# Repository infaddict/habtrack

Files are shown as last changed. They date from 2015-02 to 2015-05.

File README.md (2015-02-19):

# habtrack
High Altitude Balloon Tracker 

Written by: infaddict

Project start date: February 2015

Description: Tracking software for High Altitude Ballooning.  Includes GPS location/altitude, internal & external temperature, voltage monitor, Radio transmission and optional data logging to SD card.  

Hardware: Arduino Mini Pro 3.3V 8Mhz, uBlox M8C GPS with chip antenna, Radiometrix NTX2B-FA, 2 x DS18B20 temperature sensors, microSD breakout board (SPI), various resistors

For more information visit the UK High Altitude Society here: http://ukhas.org.uk/

Also join us on IRC: irc://irc.freenode.net/highaltitude

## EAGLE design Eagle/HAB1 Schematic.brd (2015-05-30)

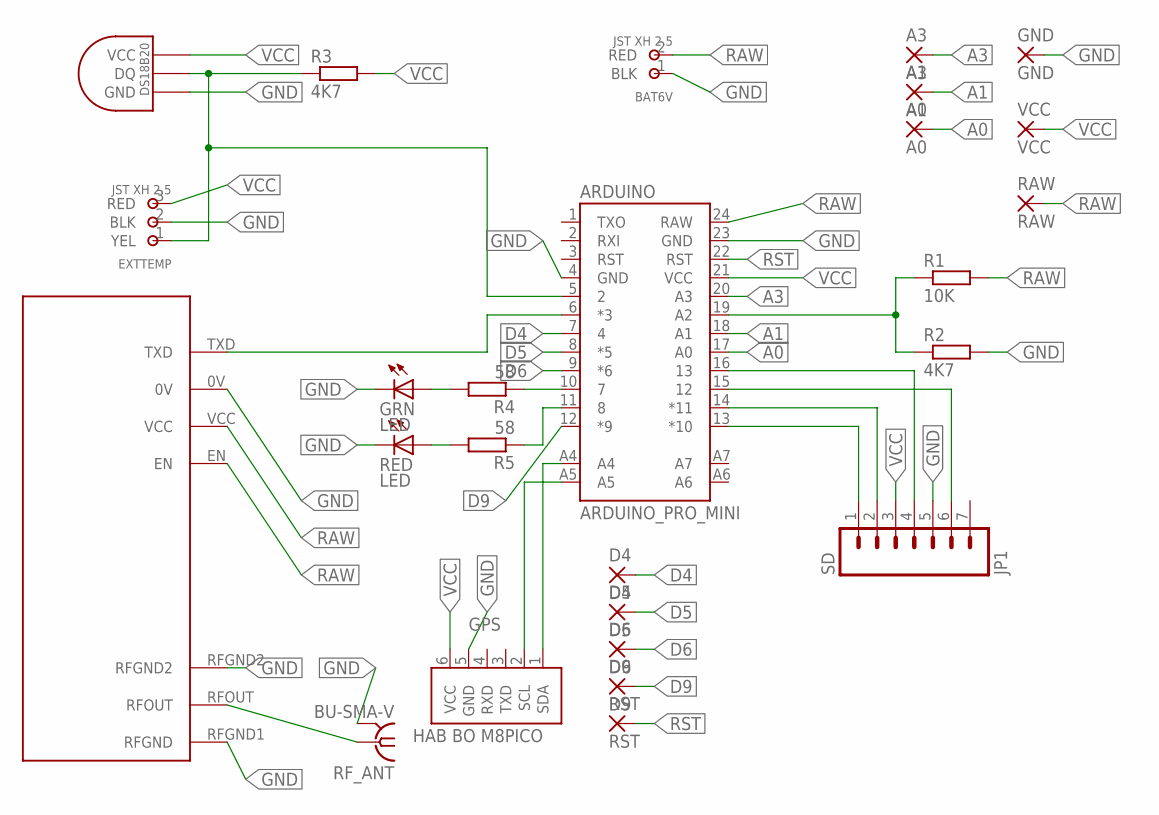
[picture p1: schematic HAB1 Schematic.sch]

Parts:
A0: A0; 1,6/0,8
A1: A1; 1,6/0,8
A3: A3; 1,6/0,8
ARDUINO: ARDUINO_PRO_MINI
BAT6V: JST-XH-2.5-2PIN-MAIL; JST-XH-2.5-2PIN-MAILE
D4: D4; 1,6/0,8
D5: D5; 1,6/0,8
D6: D6; 1,6/0,8
D9: D9; 1,6/0,8
EXTTEMP: JST-XH-2.5-2PIN-MAIL; JST-XH-2.5-2PIN-MAILE
GND: GND; 1,6/0,8
GPS: HAB-BO-M8PICONORMAL; HAB-BO-M8PICO
GRN: LED; LED3MM
INT: DS1820TO92; DS1820
JP1: SD; 1X07
R1: 10K; 0204/5
R2, R3: 4K7; 0204/5
R4, R5: 58; 0204/5
RAW: RAW; 1,6/0,8
RED: LED; LED3MM
RF_ANT: BU-SMA-V
RST: RST; 1,6/0,8
U$3: NTX2-VERTICAL
VCC: VCC; 1,6/0,8

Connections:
A0: A0.1, ARDUINO.17 (A0)
A1: A1.1, ARDUINO.18 (A1)
A2: ARDUINO.19 (A2), R1.1, R2.1
A3: A3.1, ARDUINO.20 (A3)
D2: ARDUINO.5 (2), EXTTEMP.1 (YEL), INT.DQ, R3.1
D4: ARDUINO.7 (4), D4.1
D5: ARDUINO.8 (*5), D5.1
D6: ARDUINO.9 (*6), D6.1
D9: ARDUINO.12 (*9), D9.1
GND: ARDUINO.4 (GND), ARDUINO.23 (GND), BAT6V.1 (BLK), EXTTEMP.2 (BLK), GND.1, GPS.5 (GND), GRN.K (C), INT.GND, JP1.5, R2.2, RED.K (C), RF_ANT.2, RF_ANT.3 (2), RF_ANT.4 (2), RF_ANT.5 (2), U$3.0V, U$3.RFGND1 (RFGND), U$3.RFGND2
unnamed: ARDUINO.13 (*10), JP1.1
unnamed: ARDUINO.10 (7), R4.1
unnamed: GRN.A, R4.2
unnamed: ARDUINO.11 (8), R5.1
unnamed: R5.2, RED.A
unnamed: ARDUINO.6 (*3), U$3.TXD
unnamed: ARDUINO.A5, GPS.2 (SCL)
unnamed: ARDUINO.15 (12), JP1.6
unnamed: ARDUINO.14 (*11), JP1.2
unnamed: ARDUINO.16 (13), JP1.4
unnamed: ARDUINO.A4, GPS.1 (SDA)
RAW: ARDUINO.24 (RAW), BAT6V.2 (RED), R1.2, RAW.1, U$3.EN, U$3.VCC
RFSIGNAL: RF_ANT.1, U$3.RFOUT
RST: ARDUINO.22 (RST), RST.1
VCC: ARDUINO.21 (VCC), EXTTEMP.3 (RED), GPS.6 (VCC), INT.VDD (VCC), JP1.3, R3.2, VCC.1

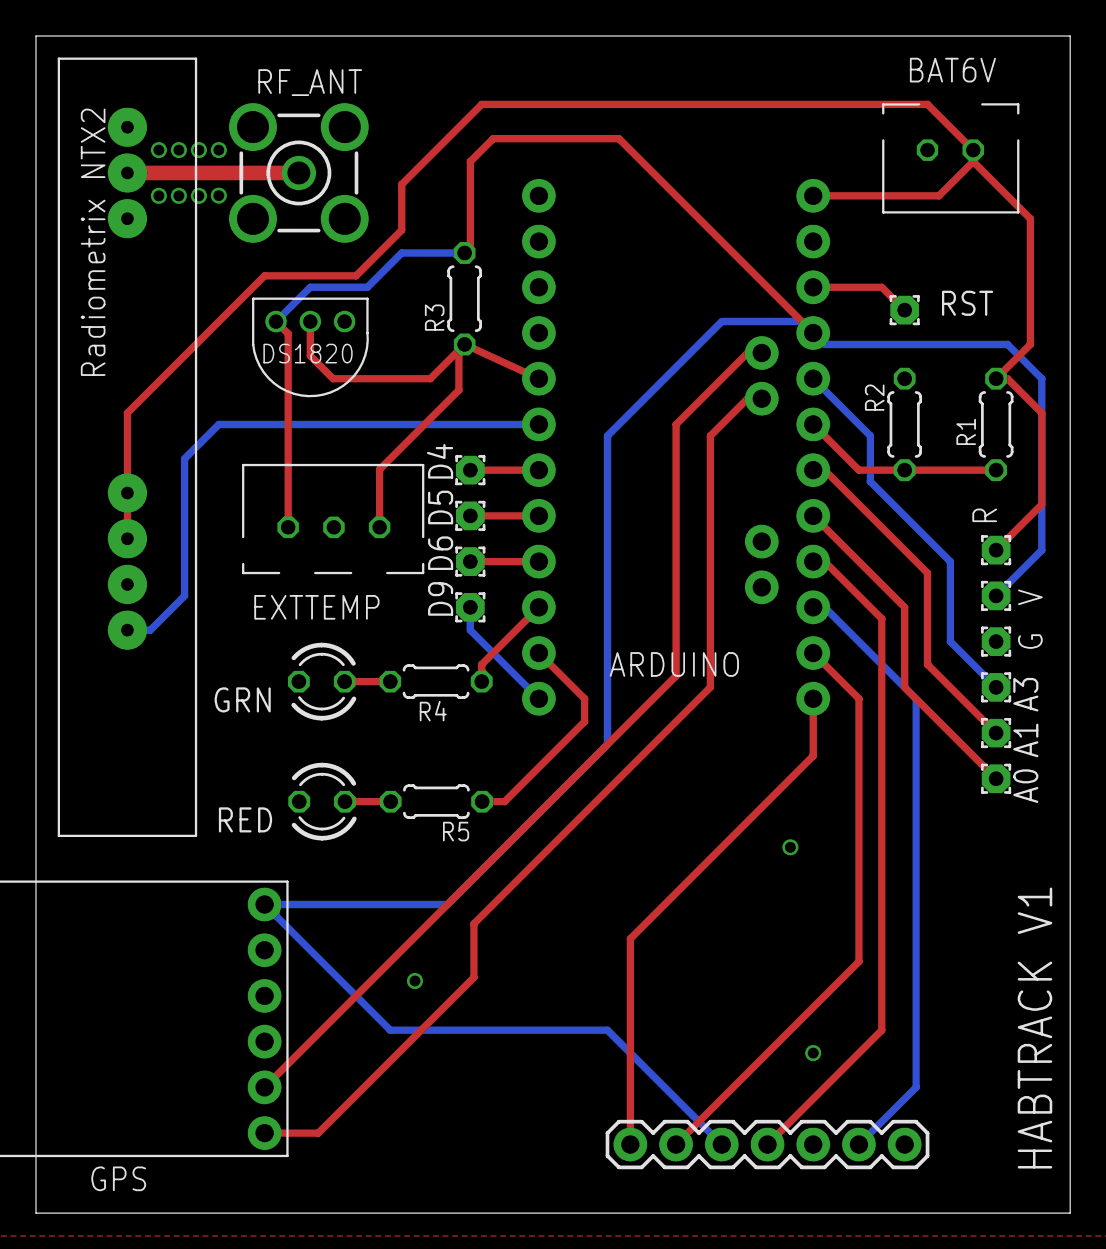
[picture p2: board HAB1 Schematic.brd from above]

Board: 2 copper layers, 57.5 x 65.4 mm, 26 parts (0 on the bottom side), 25 nets.

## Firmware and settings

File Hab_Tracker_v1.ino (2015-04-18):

////////////////////////////////////////////////////////////////////////////////
// Hab_Tracker.ino
//
// Project: HAB_Tracker
// Author:  infaddict
// Date:    February 2015
// Desc:    Main module for HAB Tracker
////////////////////////////////////////////////////////////////////////////////

#define SDLOG 1    // enable SD card logging (comment out this line to disable)

#include <Wire.h>
#include <util/crc16.h>
#include "HT_GPS.h"

const byte TX_SIZE = 85;        // must be big enough for largest RTTY sentence
const byte RED_LED_PIN = 8;     // for fatal errors
const byte GREEN_LED_PIN = 7;   // for end of setup, then later GPS lock
unsigned long timeOfLock = 0;
GPS_INFO gpsInfo;
GPS_INFO lastGoodFix;
boolean gpsLock=false;
float intTemp=0;
float extTemp=0;
float voltage=0;
long timeForGPS=0;
long timeForSensors=0;
long timeForFlightMode=180000;  // 3 minutes
boolean expectingGPSData=false;
char dataString[TX_SIZE];        
volatile char txString[TX_SIZE];   // defined as volatile as this is updated in the ISR     

////////////////////////////////////////////////////////////////////////////////
// setup()
// Setup everything we need before we enter main loop
// Called once, automatically, when Arduino starts up
////////////////////////////////////////////////////////////////////////////////
void setup()
{
  Serial.begin(115200);
  
  Serial.println();
  Serial.println(F("Start of setup."));
  Serial.print(F("Free memory = "));
  Serial.println(freeRam());
  delay(1000);
  
  // Setup LED's and turn them off
  Serial.println(F("Preparing LED's..."));
  pinMode(RED_LED_PIN, OUTPUT);
  pinMode(GREEN_LED_PIN, OUTPUT);
  digitalWrite(GREEN_LED_PIN, LOW);
  digitalWrite(RED_LED_PIN, LOW);
   
  #ifdef SDLOG
  Serial.println(F("Preparing SD Card..."));
  if (!setupSDCard())
  {
    Serial.println(F("ERROR IN SDCARD INIT!!"));
    digitalWrite(RED_LED_PIN, HIGH);
  }
  #endif
  
  // Prepare wire for master mode where we control I/O to GPS
  Wire.begin();    
   
  // Set the protocol to send and receive UBX only (disable NMEA)
  writeLog(F("Configuring TX and RX protocols..."));
  if (!sendUBX(portUBX_UBX, sizeof(portUBX_UBX)))
  {
    writeLog(F("ERROR SENDING PRT UBX-UBX COMMAND!!"));
    digitalWrite(RED_LED_PIN, HIGH);
  }
  if (!checkAck(portUBX_UBX))
  {
    writeLog(F("ACK NOT REVCV FOR PRT UBX-UBX!!"));
    digitalWrite(RED_LED_PIN, HIGH);
  }
  
  // Set the GPS to "Airborne <1g" mode suitable for high altitude
  setFlightMode();

  // Setup the Radio and interrupts for RTTY transmission
  writeLog(F("Preparing Radio..."));
  setupRadio();
  setupInterrupt();
  
  // Setup the internal and external temperature sensors.
  writeLog(F("Preparing Temperature Sensors..."));
  setupTemperature();
  
  // Finished all setup tasks so show the green LED for 5 seconds to signal this
  writeLog(F("End of setup."));
  digitalWrite(GREEN_LED_PIN, HIGH);    
  delay(5000);    
  digitalWrite(GREEN_LED_PIN, LOW);
  
}


////////////////////////////////////////////////////////////////////////////////
// loop()
// Main processing loop for Arduino.
// This loops infinitely whist Arduino is powered.
// The loop is kept mostly free and we control what we want to do when with the
// use of millis().  Requests for data will hold his loop as follows:
//    - GPS data = 800ms to 1000ms
//    - Flight mode = 800ms to 1000ms
//    - Temperature = <150ms
//    - Voltage = < 50ms
////////////////////////////////////////////////////////////////////////////////
void loop()
{  
  
  // Set the TX string to contain current known variables
  setDataString();
  
  // If we've previosuly requested GPS data then go check for it arriving.
  // This will timeout in 3 seconds if data not received.
  // Data usually arrives in < 1 second.
  if (expectingGPSData)
  {
    
    if (!checkForGPSData())
    {
      writeLog(F("ERROR READING UBX DATA!!"));
      digitalWrite(RED_LED_PIN, HIGH);
    }
    
    // Check for GPS lock.  We consider anything more than 4 satellites as good
    checkGPSLock();
    
  }
     
  // If it's time to ask for GPS data then do it
  if (millis() > timeForGPS)
  {
    expectingGPSData = true;
    
    // Send request for a NAV-PVT message (position, velocity, time)
    if (!sendUBX(reqNAV_PVT, sizeof(reqNAV_PVT)))
    {
      writeLog(F("ERROR SENDING NAV PVT COMMAND!!"));
      digitalWrite(RED_LED_PIN, HIGH);
    }
   
    // set up when we next want to do this
    timeForGPS = millis() + 3000;   // 3 seconds
  }
    
  // If it's time to ask for sensor data then do it
  if (millis() > timeForSensors)
  {
    // go and get temperature data
    checkTemperature();

    // go and get voltage data
    voltage = getVoltage();
    
    // set up when we next want to do this
    timeForSensors = millis() + 10000;   // 10 seconds
  }
  
  // If it's time to set the flight mode then do it
  // Note that the GPS should remain in flight mode from the setup
  // This is just a precaution in case of a reboot midair or other issue
  if (millis() > timeForFlightMode)
  {
    setFlightMode();
    timeForFlightMode = millis() + 180000;  // 3 minutes 
  }
  
}

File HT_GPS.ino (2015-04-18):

////////////////////////////////////////////////////////////////////////////////
// HT_GPS.ino
//
// Project: HAB_Tracker
// Author:  infaddict
// Date:    February 2015
////////////////////////////////////////////////////////////////////////////////

#include <Wire.h>  // required for I2C/DDC communication

byte UBXstate = 0;
unsigned char Checksum_A = 0;
unsigned char Checksum_B = 0;
unsigned char UBXclass;
unsigned char UBXid;
unsigned char UBXlengthLSB;
unsigned char UBXlengthMSB;
byte UBXlength;
unsigned char UBXpayloadIdx;
unsigned char UBXbuffer[UBX_MAX_PAYLOAD];
unsigned char UBXckA;
unsigned char UBXckB;


////////////////////////////////////////////////////////////////////////////////
// setFlightMode()
// Sets the GPS to Airborne/Flight mode for accurate positioning above 12,500m
////////////////////////////////////////////////////////////////////////////////
void setFlightMode()
{
  writeLog(F("Setting airborne mode..."));
  if (!sendUBX(airborne1g, sizeof(airborne1g)))
  {
    writeLog(F("ERROR SENDING FLIGHT MODE COMMAND!!"));
    digitalWrite(RED_LED_PIN, HIGH);
  }
  if (!checkAck(airborne1g))
  {
    writeLog(F("ACK NOT RECV FOR FLIGHT MODE!!"));
    digitalWrite(RED_LED_PIN, HIGH);
  }
}

////////////////////////////////////////////////////////////////////////////////
// readUBX()
// Requests the maximum buffer length from the GPS and reads the data.
// Uses a state machine to process UBX bytes, including checks for payload 
// length and checksum.
// Resultant UBX message (if any) is placed into UBXbuffer[]
// Returns true is all ok
// Returns false if bad payload or checksum detected.
////////////////////////////////////////////////////////////////////////////////
boolean checkForGPSData()
{
  long gpsTimeout = millis() + 3000;  // 3 second timeout waiting for data
  boolean timeout = false;
  boolean endOfMessage = false;
  
  // Loop looking for data until end of message or we reach timeout period
  while(!endOfMessage && !timeout)
  {   
    if (millis() > gpsTimeout)
    {
      timeout = true;
    }
    
    // If there is no GPS data available, request another buffers worth of data
    if (!GPSdataAvailable())
    {
      setGPSforRead();
    }
    else
    {
      // There is GPS data available so read it until there is no more or end of message
      unsigned char uChar;
      while (GPSdataAvailable() && !endOfMessage)
      {
        uChar = readGPSchar();  // Read 1 char (byte) from GPS
        
        //Serial.print(uChar,HEX);
        //Serial.print(" ");
        
        // Start the state machine to process the message bytes
        switch(UBXstate)
        {
          case 0:    // Awaiting Sync Char 1
            if (uChar == UBX_SYNC_CHAR1)
            {
              UBXstate++;
            }
            break;
          case 1:    // Awauting Sync Char 2
            if (uChar == UBX_SYNC_CHAR2)
            {
              UBXstate++;
            }
            else
            {
              UBXstate = 0;    // Wrong sequence so start again
            }
            break;
          case 2:    // Awaiting Class
            UBXclass = uChar;
            UBXchecksum(UBXclass);
            UBXstate++;
            break;
          case 3:    // Awaiting Id
            UBXid = uChar;
            UBXchecksum(UBXid);
            UBXstate++;
            break;
          case 4:    // Awaiting Length LSB (little endian so LSB is first)
            UBXlengthLSB = uChar;
            UBXchecksum(UBXlengthLSB);
            UBXstate++;       
            break;
          case 5:    // Awaiting Length MSB
            UBXlengthMSB = uChar;
            UBXchecksum(UBXlengthMSB);
            UBXstate++;
            UBXpayloadIdx = 0;
            UBXlength = (byte)(UBXlengthMSB << 8) | UBXlengthLSB;  // convert little endian MSB & LSB into integer
            if (UBXlength >= UBX_MAX_PAYLOAD)
            {
              writeLog(F("UBX PAYLOAD BAD LENGTH!!"));
              UBXstate=0;    // Bad data received so reset to start again
              Checksum_A=0;
              Checksum_B=0;
              return false;
            }
            break;
          case 6:    // Awaiting Payload
            if (UBXpayloadIdx < UBXlength)
            {
              UBXbuffer[UBXpayloadIdx] = uChar;
              UBXchecksum(uChar);
              UBXpayloadIdx++;
              if (UBXpayloadIdx == UBXlength)
              {
                UBXstate++;  // Just processed last byte of payload, so move on
              }
            }         
            break;
          case 7:    // Awaiting Checksum 1
            UBXckA = uChar;
            UBXstate++;
            break;
          case 8:    // Awaiting Checksum 2
            UBXckB = uChar;
            if ((Checksum_A == UBXckA) && (Checksum_B == UBXckB))    // Check the calculated checksums match actual checksums
            {
              // Checksum is good so parse the message
              parseUBX();
              endOfMessage = true;
            }
            else
            {
              writeLog(F("UBX PAYLOAD BAD CHECKSUM!!"));
              return false;
            }
            
            UBXstate=0;    // Start again at 0
            Checksum_A=0;
            Checksum_B=0;
            break;      
        }
              
      } 
    
    }
    
  } // while !eom or !timeout
  
  // Only when received all expected data with checksum do we stop
  expectingGPSData = false;

  if (timeout)
  {
    return false; // timeout
  }
  else
  {
    return true;  // everything ok
  }
    
}
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

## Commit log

2015-03-05 Add Eagle files & datasheets
    [HAB1 Schematic.brd, HAB1 Schematic.sch]
2015-05-30 Updated PCB
    [HAB1 Schematic.brd, HAB1 Schematic.sch]

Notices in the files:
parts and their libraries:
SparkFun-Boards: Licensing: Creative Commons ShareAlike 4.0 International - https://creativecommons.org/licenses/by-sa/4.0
